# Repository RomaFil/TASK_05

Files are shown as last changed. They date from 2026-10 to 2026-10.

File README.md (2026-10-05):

# TASK_05 — плата Motion Logger для Raspberry Pi 5 і корпус для 3D-друку

Завдання: намалювати в Altium плату-модуль, яка вставляється датчиками й одягається на Raspberry Pi, експортувати її у STEP, відкрити у Fusion і зробити корпус, у якому стоять Raspberry Pi і плата. Окремо — код під Raspberry Pi (поки демонстраційний).

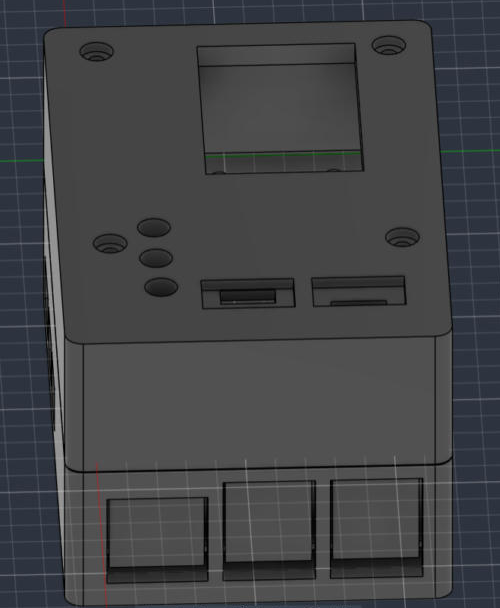
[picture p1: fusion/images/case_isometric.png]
Корпус у Fusion


## Структура репозиторію

```
TASK_05/
├── altium/                      проєкт Altium Designer (відкривати Motion_Logger.PrjPcb)
│   ├── Motion_Logger.PrjPcb     файл проєкту
│   ├── Schematic/Sheet2.SchDoc  схема
│   ├── PCB/PCB2.PcbDoc          плата 85 × 56 мм, 2 шари
│   ├── Library/                 власні бібліотеки: символи (Schlib2) і футпринти (PcbLib2)
│   ├── Fab/                     Gerber + свердління (ZIP) і STEP плати для Fusion
│   ├── Project Outputs for Motion_Logger/   звіт перевірки правил (DRC), 0 помилок
│   └── CAMtastic*.Cam           службові файли Altium для Gerber
├── fusion/                      проєкт Fusion
│   ├── Motion_Logger_Case.f3d   модель (архів Fusion: відкривається через File → Open → Open from my computer)
│   ├── output/                  результат: STL для друку, STEP збірки
│   ├── inputs/                  вхідні STEP: плата з Altium і спрощена модель Pi 5
│   ├── script/                  скрипт Fusion (Python), що будує корпус
│   ├── tools/                   допоміжні скрипти перевірки (Python)
│   └── images/                  картинки: вигляд моделі і перерізи
└── code/                        демонстраційний код для Raspberry Pi (Python), буде змінюватися
```

## 1. Altium: плата Motion Logger

Плата розміром 85 × 56 мм (як Raspberry Pi 5) одягається на гребінку 2×20 Raspberry Pi. Кріпильні отвори ⌀2,7 мм на 58 × 49 мм збігаються з отворами Pi. Товщина 1,6 мм, 2 шари, модулі стоять зверху. Власних джерел живлення на платі нема: 3,3 В беруться з Pi.

Модулі й елементи на платі:

| Позначення | Що це | Інтерфейс |
|---|---|---|
| `U1` | GPS NEO-6M (модуль HW-623) | UART |
| `U2` | GY-87 (HW-290): MPU6050 + HMC5883L + BMP180 | I2C |
| `U3` | ADXL345 (модуль GY-291) | SPI |
| `SW1`, `SW2` | дві кнопки (HW-483, KY-004) | GPIO |
| `D1`–`D3` + `R1`–`R3` | RGB-світлодіод з трьох окремих світлодіодів і резисторів | GPIO |
| `J1` | гніздо 2×20 під Raspberry Pi 5 | — |

### Підключення пінів Pi 5

| Пін `J1` | GPIO | Мережа | Куди |
|---|---|---|---|
| 1, 17 | 3V3 | `VCC` | живлення модулів і кнопок |
| 6, 9, 14, 20, 25, 30, 34, 39 | GND | `GND` | земля |
| 3 / 5 | GPIO2 / GPIO3 | `I2C_SDA` / `I2C_SCL` | GY-87 |
| 7 / 29 | GPIO4 / GPIO5 (uart2) | `UART_TX` / `UART_RX` | GPS |
| 19 / 21 / 23 / 24 | GPIO10 / 9 / 11 / 8 | `SPI_MOSI` / `MISO` / `SCLK` / `CS0` | ADXL345 |
| 11 / 33 | GPIO17 / GPIO13 | `BTN` / `BTN2` | кнопки `SW1` / `SW2` |
| 13 / 15 / 31 | GPIO27 / GPIO22 / GPIO6 | `LED_R` / `LED_G` / `LED_B` | світлодіоди |

Правила проєктування пройдено без порушень (DRC: 0). Звіт: `altium/Project Outputs for Motion_Logger/`.

Файли для виробництва: `altium/Fab/Motion_Logger_Gerber.zip` (шари, контур, свердління металізованих і неметалізованих отворів окремо). STEP для Fusion: `altium/Fab/Motion_Logger_board.step`.

Версія Altium Designer, у якій зроблено проєкт: 26.10.1.

## 2. Fusion: корпус

Корпус складається з **основи** і **кришки**. Усередині: Raspberry Pi 5 на 4 стійках, над ним на стійках M2.5 плата Motion Logger.

Модель збудовано скриптом Fusion (Python API) за розмірами зі STEP плати з Altium і офіційного STEP Raspberry Pi 5. Опис кроків: розділ «Як зроблено» нижче.

Головні розміри (мм; система координат: лівий нижній кут плати = (0;0), Z = 0 — верх плати):

| Що | Значення |
|---|---|
| Зовнішній розмір корпусу | 95,6 × 65,0 × 52,9 |
| Стінки / дно / верх кришки | 3,0 / 3,0 / 4,0 |
| Висота від верху плати Pi до низу плати Motion Logger | 20,0 (довжина стійок M2.5) |
| Висота над платою Motion Logger | 20,0 (гребінка 8,5 + модуль 10 + запас 1,5) |
| Стійки під Pi | ⌀7, висота 3,0, гвинти M2.5 знизу |
| Кришка | 4 гвинти M2.5 згори крізь труби кришки і плату в стійки |

Вікна й отвори:
- Права стіна: Ethernet і два блоки USB Raspberry Pi.
- Нижня стіна: USB-C живлення і два micro-HDMI.
- Ліва стіна: карта microSD.
- Дно: 5 щілин під процесором (пасивне охолодження, кулера нема).
- Кришка: 3 світловоди під світлодіоди, вікно на весь модуль GPS, дві ніші під модулі кнопок зі щілиною для дротів.

Перевірки (скрипти в `fusion/tools/`): перетинів основи і кришки з платою та Pi немає, найменший зазор основи до роз'ємів Pi 0,74 мм, перерізи в `fusion/images/`.

### Друк
Використовуй STL з `fusion/output/`:
- `Case_Base_print.stl` — основа, друкувати як є (дном вниз);
- `Case_Lid_print_flipped.stl` — кришка, уже перевернута верхом на стіл.

Зазори 0,2–0,3 мм і стінки 3 мм — загальні правила, не перевірені на конкретному принтері. Матеріал і принтер на момент створення не обрано.

### Як відкрити й змінити
- Модель: `File → Open → Open from my computer` → `fusion/Motion_Logger_Case.f3d`.
- Змінити розмір: поправ параметри на початку `fusion/script/MotionLoggerCase.py` (`H`, `CAV`, `W`, вікна). У Fusion: `Utilities → Add-Ins → Scripts and Add-Ins` → `+` → `Script or add-in from device` → вибрати папку `fusion/script` → `Run`. Скрипт створить новий документ і запише STL/STEP в `fusion/output/`.

## 3. Код для Raspberry Pi
Папка `code/` містить **демонстраційний** код (`motion_logger_demo.py`): читає MPU6050, ADXL345, GPS і кнопки, пише CSV-лог, показує стан світлодіодом. Він простий, на реальному залізі не перевірений і буде змінюватися. Опис і запуск: [code/README.md](code/README.md).

## Як зроблено корпус (коротко)
1. Плату намальовано в Altium, STEP експортовано (`altium/Fab/Motion_Logger_board.step`). У ньому лише плата, гніздо `J1`, резистори й світлодіоди; виводи резисторів і світлодіодів звисали на 27 мм униз.
2. Офіційний STEP Raspberry Pi 5 (Raspberry Pi Ltd, ліцензія MIT) завважкий (77 МБ, 2689 тіл). З нього зчитано габарити роз'ємів і зроблено спрощену модель `fusion/inputs/pi5_proxy.step` (`fusion/tools/make_pi5_proxy.py`). У платі лишено тіло плати, гніздо й колби світлодіодів без виводів (`fusion/tools/make_plate_input.py`).
3. Висоту між Pi і платою розраховано за STEP: роз'єми USB стоять на 16,2 мм над платою Pi, пластик гребінки Pi 2,57 мм, штирі ще 6,0 мм.
4. Скрипт `fusion/script/MotionLoggerCase.py` імпортує обидва STEP, ставить їх у потрібні місця й будує основу та кришку (тіла з об'ємними логічними операціями), експортує STL і STEP.
5. Результат перевірено в Python (OpenCascade): перетини, зазори, перерізи.

Під час роботи використовувався ШІ-асистент Claude (Anthropic): він читав STEP-файли, рахував розміри, писав скрипт Fusion і перевірки. Рішення щодо конструкції (висота стека, гвинти, кнопки в кришці, живлення тільки через USB-C Pi, вікно GPS, товщина стінок) ухвалював я.

## Ліцензії та джерела
- 3D-модель Raspberry Pi 5: Raspberry Pi Ltd, MIT, <https://datasheets.raspberrypi.com/rpi5/RaspberryPi5-step.zip> (в репозиторії лише спрощена модель, зроблена з її розмірів).

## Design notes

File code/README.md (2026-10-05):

# Код для Raspberry Pi 5 (демонстрація)

> **Це лише демонстрація. Код простий, на реальному залізі не перевірений і буде змінюватися.**
> Фінальна версія з'явиться пізніше (буфер, потоки, фільтр руху, запуск при старті системи).

Що робить `motion_logger_demo.py`: раз на секунду читає датчики й пише рядок у CSV-лог.

| Що | Як | Піни / адреса |
|---|---|---|
| MPU6050 (модуль GY-87) | I2C1, бібліотека `smbus2` | пін 3 (SDA), пін 5 (SCL), адреса `0x68` |
| ADXL345 (модуль GY-291) | SPI0, бібліотека `spidev` | піни 19, 21, 23, CE0 = пін 24 |
| GPS NEO-6M | UART, бібліотека `pyserial`, рядки `$..RMC` з перевіркою контрольної суми | піни 7 (TX), 29 (RX), порт `/dev/ttyAMA2` |
| Кнопка 1 / 2 | GPIO17 / GPIO13, `libgpiod` | пауза запису / позначка `MARK` у логу |
| Світлодіод | GPIO27 (червоний), GPIO22 (зелений), GPIO6 (синій) | червоний — нема GPS-фіксації, зелений — є, синій — запис |

Якщо датчик чи бібліотека недоступні, програма пише про це і працює далі без нього (у лозі порожні значення).

## Як запустити (не перевірено на Pi)

1. У `/boot/firmware/config.txt` увімкнути інтерфейси й перезавантажити:
   ```
   dtparam=i2c_arm=on
   dtparam=spi=on
   dtoverlay=uart2-pi5
   ```
   Назву overlay `uart2-pi5` перевір командою `ls /boot/firmware/overlays | grep uart`.
2. Встановити бібліотеки:
   ```
   sudo apt install python3-libgpiod
   pip install -r requirements.txt --break-system-packages
   ```
3. Перевірити датчики: `i2cdetect -y 1` (має бути `68`), `ls /dev/spidev0.0`, `ls /dev/ttyAMA*`.
4. Запустити:
   ```
   python3 motion_logger_demo.py
   ```
   Вихід: `Ctrl+C`. Лог: `motion_log.csv` у поточній папці (інша назва: змінна `LOG_FILE`; інший порт GPS: змінна `GPS_PORT`).

## Перевірка розбору даних (без Raspberry Pi)
```
python test_parsers.py
```
Перевіряє контрольну суму NMEA, розбір `$GPRMC` і перерахунок «сирих» байтів MPU6050 та ADXL345 у фізичні величини. Працює на будь-якому комп'ютері.

## Що не перевірено
- Робота на реальному Raspberry Pi 5 з платою (усі піни взято з таблиці підключень, див. [головний README](../README.md#підключення-пінів-pi-5)).
- Назва overlay UART і порт `/dev/ttyAMA2`.
- Чи дає натиснута кнопка 1 (`BUTTON_ACTIVE_HIGH = True` у коді): залежить від модуля KY-004.
- Номер `gpiochip`: програма шукає чип RP1 автоматично, запасний варіант `/dev/gpiochip0`.

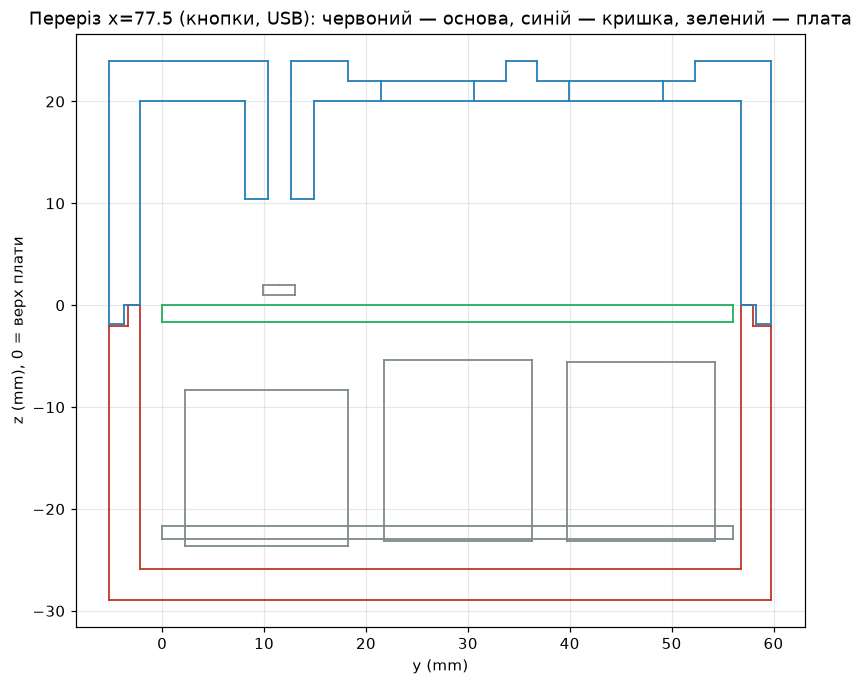
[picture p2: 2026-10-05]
fusion/images/sec_x775.png

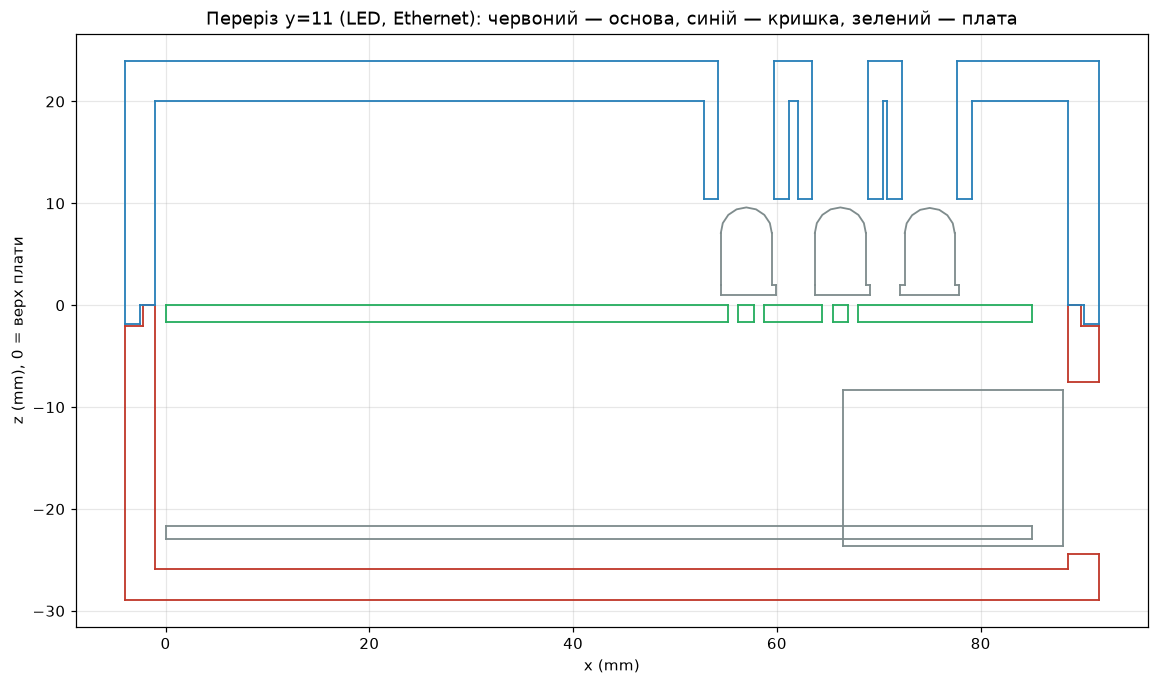
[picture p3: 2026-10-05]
fusion/images/sec_y11.png

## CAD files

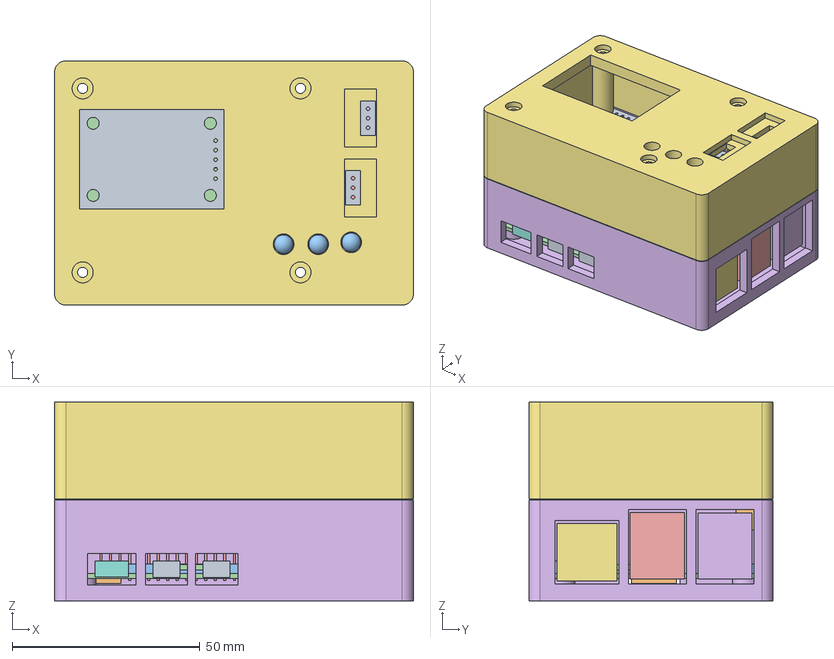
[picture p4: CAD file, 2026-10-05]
fusion/output/Motion_Logger_case_assembly.step
95.6 x 65.0 x 52.9 mm

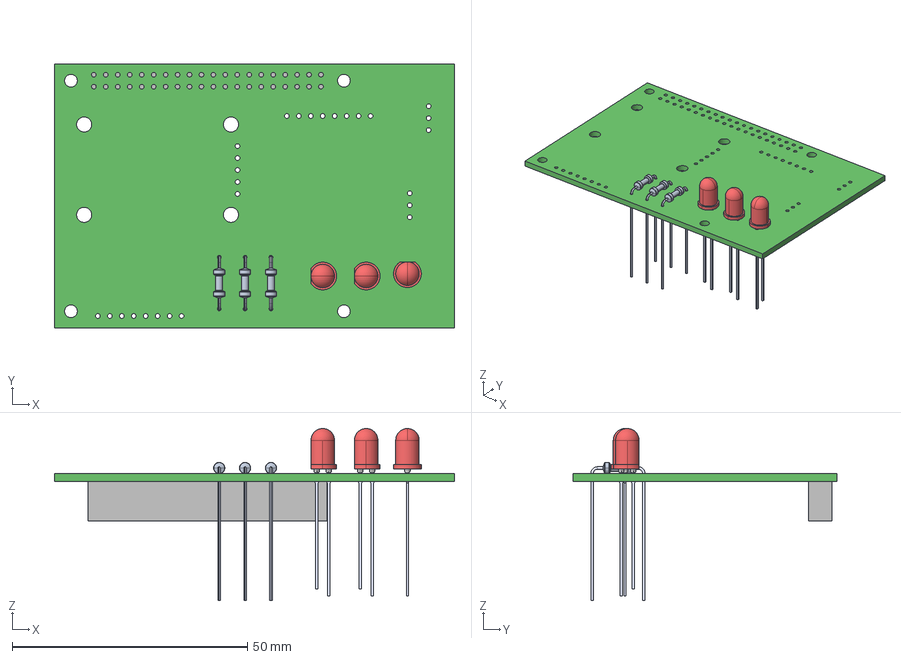
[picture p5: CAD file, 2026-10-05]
altium/Fab/Motion_Logger_board.step
85.0 x 56.0 x 36.6 mm
Extruded
WP7113ID_WP7113ID x 3

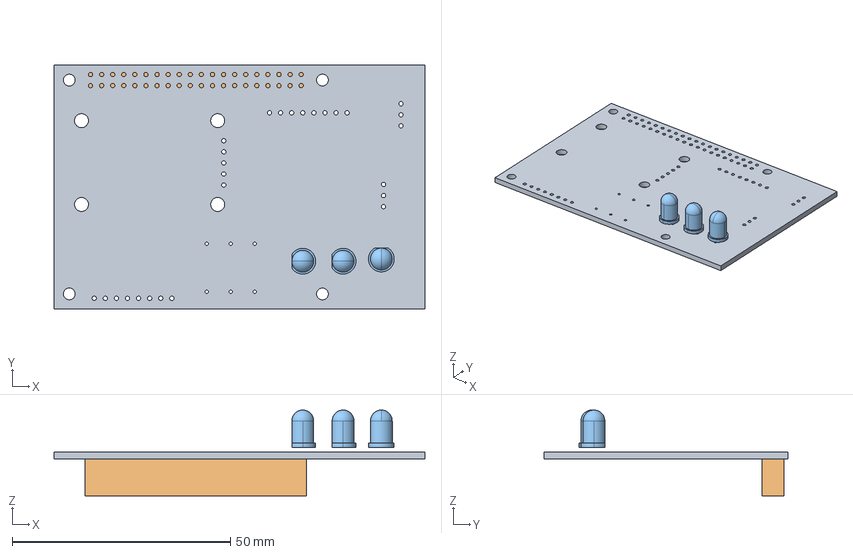
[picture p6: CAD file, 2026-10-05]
fusion/inputs/plate_clean.step
85.0 x 56.0 x 19.7 mm

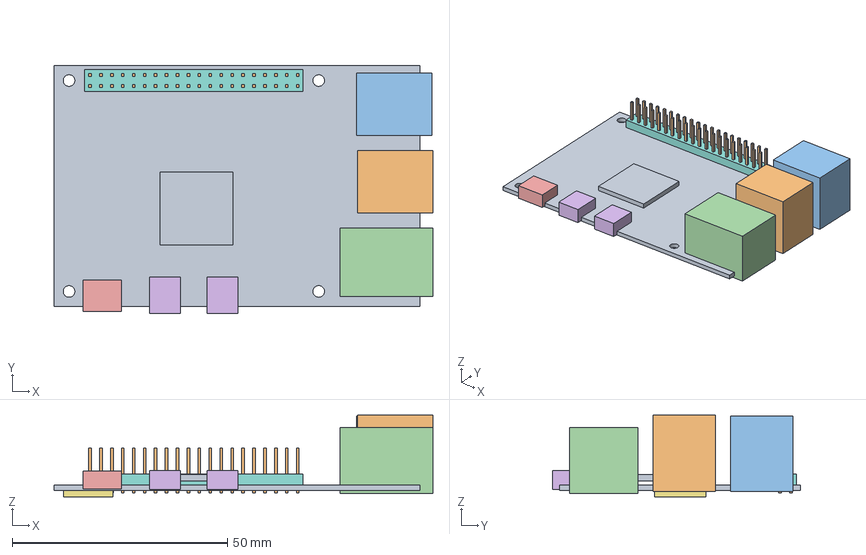
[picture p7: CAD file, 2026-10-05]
fusion/inputs/pi5_proxy.step
88.0 x 57.6 x 19.0 mm

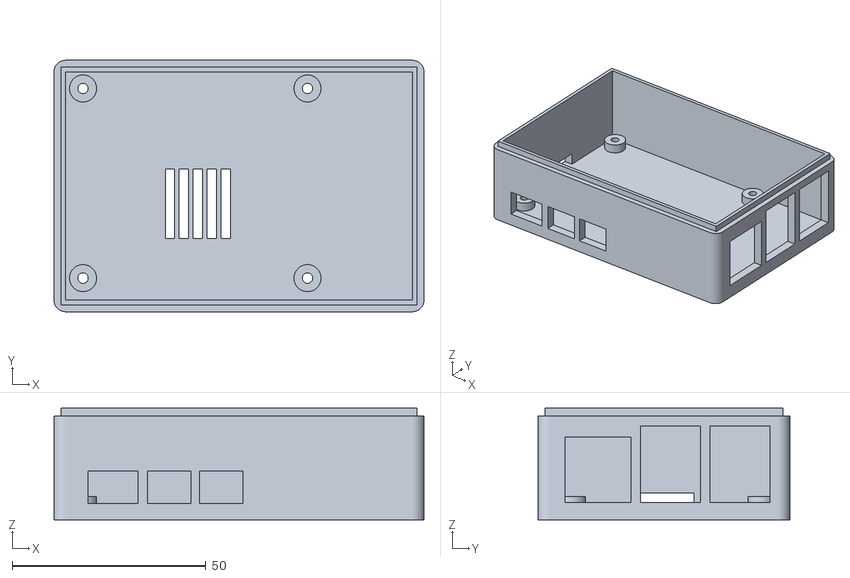
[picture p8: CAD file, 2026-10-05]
fusion/output/Case_Base_print.stl
95.6 x 65.0 x 28.9

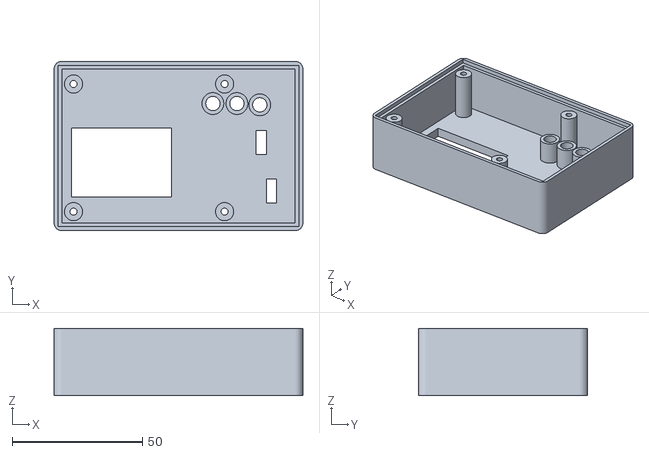
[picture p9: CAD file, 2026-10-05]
fusion/output/Case_Lid_print_flipped.stl
95.6 x 65.0 x 25.8

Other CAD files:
fusion/Motion_Logger_Case.f3d

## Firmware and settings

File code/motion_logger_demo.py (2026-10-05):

#!/usr/bin/env python3
"""Motion Logger: ДЕМОНСТРАЦІЙНИЙ код для Raspberry Pi 5 (буде змінюватись).

Раз на секунду читає датчики, пише рядок у CSV-лог і показує стан світлодіодом:
  - MPU6050 (модуль GY-87, I2C, адреса 0x68): прискорення, швидкість обертання, температура;
  - ADXL345 (модуль GY-291, SPI0, CE0): прискорення;
  - GPS NEO-6M (UART): координати, швидкість, чи є фіксація;
  - кнопка 1 (GPIO17): пауза / відновлення запису;
  - кнопка 2 (GPIO13): позначка «MARK» у наступному рядку логу;
  - світлодіод: червоний — нема GPS-фіксації, зелений — є, синій блимає при записі.

Піни взято з таблиці підключень плати (altium/, README.md). На реальному залізі НЕ перевірено.
Якщо якийсь датчик або бібліотека недоступні, програма це пише й продовжує без нього.
"""
import csv
import glob
import os
import sys
import time

# ---------------- налаштування (піни за схемою плати) ----------------
LED_R, LED_G, LED_B = 27, 22, 6          # GPIO світлодіодів (через резистори на платі)
BTN1, BTN2 = 17, 13                      # GPIO кнопок
BUTTON_ACTIVE_HIGH = True                # припущення: натиснута кнопка дає 1; перевірити на залізі
I2C_BUS, MPU_ADDR = 1, 0x68              # I2C1 (піни 3 і 5), AD0 на землі
SPI_BUS, SPI_CS = 0, 0                   # SPI0, CE0 (пін 24)
GPS_PORT = os.environ.get("GPS_PORT", "/dev/ttyAMA2")   # uart2 на GPIO4/5; назву overlay не перевірено
GPS_BAUD = 9600
LOG_FILE = os.environ.get("LOG_FILE", "motion_log.csv")
PERIOD_S = 1.0


# ---------------- розбір даних (працює і без заліза, є тести) ----------------
def to_signed16(hi, lo):
    v = (hi << 8) | lo
    return v - 65536 if v & 0x8000 else v


def mpu6050_convert(raw14):
    """14 байт з регістра 0x3B → (accel_g[3], temp_c, gyro_dps[3]); діапазони ±2 g і ±250 °/с."""
    w = [to_signed16(raw14[i], raw14[i + 1]) for i in range(0, 14, 2)]
    accel = tuple(round(v / 16384.0, 4) for v in w[0:3])
    temp = round(w[3] / 340.0 + 36.53, 2)
    gyro = tuple(round(v / 131.0, 3) for v in w[4:7])
    return accel, temp, gyro


def adxl345_convert(raw6):
    """6 байт з регістра 0x32 → прискорення в g (повна роздільність ≈ 3,9 мг/біт)."""
    return tuple(round(to_signed16(raw6[i + 1], raw6[i]) * 0.0039, 4) for i in range(0, 6, 2))


def nmea_checksum_ok(line):
    """Перевірка контрольної суми NMEA: XOR символів між '$' і '*'."""
    if not line.startswith("$") or "*" not in line:
        return False
    body, _, tail = line[1:].partition("*")
    calc = 0
    for ch in body:
        calc ^= ord(ch)
    try:
        return calc == int(tail[:2], 16)
    except ValueError:
        return False


def _deg(value, hemi):
    """ddmm.mmmm → градуси."""
    if not value:
        return None
    dot = value.index(".")
    deg = float(value[:dot - 2]) + float(value[dot - 2:]) / 60.0
    return -deg if hemi in ("S", "W") else deg


def parse_rmc(line):
    """$GPRMC / $GNRMC → dict(fix, lat, lon, speed_kmh) або None, якщо рядок не підходить."""
    if not nmea_checksum_ok(line):
        return None
    f = line.split("*")[0].split(",")
    if f[0][3:] != "RMC" or len(f) < 8:
        return None
    fix = f[2] == "A"
    return {
        "fix": fix,
        "lat": _deg(f[3], f[4]) if fix else None,
        "lon": _deg(f[5], f[6]) if fix else None,
        "speed_kmh": round(float(f[7]) * 1.852, 2) if fix and f[7] else None,
    }


# ---------------- робота із залізом ----------------
class Leds:
    """Світлодіоди й кнопки через libgpiod 2.x (пакет python3-libgpiod)."""

    def __init__(self):
        self.req = None
        try:
            import gpiod
            from gpiod.line import Bias, Direction, Value
            self.Value = Value
            path = self._find_chip(gpiod)
            out = gpiod.LineSettings(direction=Direction.OUTPUT, output_value=Value.INACTIVE)
            inp = gpiod.LineSettings(direction=Direction.INPUT,
                                     bias=Bias.PULL_DOWN if BUTTON_ACTIVE_HIGH else Bias.PULL_UP)
            self.req = gpiod.request_lines(path, consumer="motion-logger", config={
                LED_R: out, LED_G: out, LED_B: out, BTN1: inp, BTN2: inp})
            print("GPIO: чип", path)
        except Exception as e:
            print("GPIO недоступний:", e)

    @staticmethod
    def _find_chip(gpiod):
        # На Pi 5 піни гребінки належать мікросхемі RP1; номер gpiochip залежить від ядра.
        for path in sorted(glob.glob("/dev/gpiochip*")):
            try:
                if "rp1" in gpiod.Chip(path).get_info().label.lower():
                    return path
            except Exception:
                pass
        return "/dev/gpiochip0"

    def set(self, r=False, g=False, b=False):
        if self.req:
            V = self.Value
            self.req.set_values({LED_R: V.ACTIVE if r else V.INACTIVE,
                                 LED_G: V.ACTIVE if g else V.INACTIVE,
                                 LED_B: V.ACTIVE if b else V.INACTIVE})

    def pressed(self, pin):
        if not self.req:
            return False
        active = self.req.get_value(pin) == self.Value.ACTIVE
        return active if BUTTON_ACTIVE_HIGH else not active


class Mpu6050:
    def __init__(self):
        self.bus = None
        try:
            from smbus2 import SMBus
            self.bus = SMBus(I2C_BUS)
            self.bus.write_byte_data(MPU_ADDR, 0x6B, 0x00)   # вийти зі сну
            print("MPU6050: ок")
        except Exception as e:
            print("MPU6050 недоступний:", e)
            self.bus = None

    def read(self):
        if not self.bus:
            return None
        try:
            return mpu6050_convert(self.bus.read_i2c_block_data(MPU_ADDR, 0x3B, 14))
        except Exception:
            return None


class Adxl345:
    def __init__(self):
        self.spi = None
        try:
            import spidev
            self.spi = spidev.SpiDev()
            self.spi.open(SPI_BUS, SPI_CS)
            self.spi.max_speed_hz = 1_000_000
            self.spi.mode = 0b11                              # ADXL345 працює в режимі SPI 3
            devid = self.spi.xfer2([0x80 | 0x00, 0x00])[1]   # регістр DEVID, має бути 0xE5
            if devid != 0xE5:
                raise RuntimeError("DEVID=0x%02X, очікувалось 0xE5" % devid)
            self.spi.xfer2([0x2D, 0x08])                      # POWER_CTL: режим вимірювання
            self.spi.xfer2([0x31, 0x08])                      # DATA_FORMAT: повна роздільність, ±2 g
            print("ADXL345: ок")
        except Exception as e:
            print("ADXL345 недоступний:", e)
            self.spi = None

    def read(self):
        if not self.spi:
            return None
        try:
            return adxl345_convert(self.spi.xfer2([0xC0 | 0x32] + [0] * 6)[1:])
        except Exception:
            return None


class Gps:
    def __init__(self):
        self.ser = None
        self.last = {"fix": False, "lat": None, "lon": None, "speed_kmh": None}
        try:
            import serial
            self.ser = serial.Serial(GPS_PORT, GPS_BAUD, timeout=0.2)
            print("GPS: порт", GPS_PORT)
        except Exception as e:
            print("GPS недоступний:", e)

    def poll(self):
        """Зчитує все, що накопичилось у порту, і оновлює останнє значення з $xxRMC."""
        if not self.ser:
            return self.last
        try:
            for raw in self.ser.read(self.ser.in_waiting or 1).decode("ascii", "ignore").splitlines():
                data = parse_rmc(raw.strip())
                if data:
                    self.last = data
        except Exception:
            pass
        return self.last


# ---------------- головний цикл ----------------
def main():
    leds, mpu, adxl, gps = Leds(), Mpu6050(), Adxl345(), Gps()
    new_file = not os.path.exists(LOG_FILE)
    log = open(LOG_FILE, "a", newline="", encoding="utf-8")
    out = csv.writer(log)
    if new_file:
        out.writerow(["time", "mark", "mpu_ax_g", "mpu_ay_g", "mpu_az_g", "mpu_temp_c",
                      "gyro_x_dps", "gyro_y_dps", "gyro_z_dps",
                      "adxl_x_g", "adxl_y_g", "adxl_z_g", "gps_fix", "lat", "lon", "speed_kmh"])
    paused, mark, was_pressed1, was_pressed2 = False, False, False, False
    print("Запис у", LOG_FILE, "(Ctrl+C — вихід; кнопка 1 — пауза, кнопка 2 — позначка)")
    try:
        while True:
            t0 = time.time()
            p1, p2 = leds.pressed(BTN1), leds.pressed(BTN2)
            if p1 and not was_pressed1:
                paused = not paused
                print("пауза" if paused else "запис відновлено")
            if p2 and not was_pressed2:
                mark = True
            was_pressed1, was_pressed2 = p1, p2

            fix = gps.poll()
            if not paused:
                m, a = mpu.read(), adxl.read()
                accel, temp, gyro = m if m else ((None,) * 3, None, (None,) * 3)
                row = [time.strftime("%Y-%m-%d %H:%M:%S"), "MARK" if mark else "", *accel, temp, *gyro,
                       *(a if a else (None,) * 3), int(fix["fix"]), fix["lat"], fix["lon"], fix["speed_kmh"]]
                out.writerow(row)
                log.flush()
                print(row)
                mark = False
                leds.set(r=not fix["fix"], g=fix["fix"], b=True)   # синій блимає разом із записом
                time.sleep(0.1)
            leds.set(r=not fix["fix"] and not paused, g=fix["fix"] and not paused, b=False)
            time.sleep(max(0.0, PERIOD_S - (time.time() - t0)))
    except KeyboardInterrupt:
        print("\nвихід")
    finally:
        leds.set()
        log.close()


if __name__ == "__main__":
    sys.exit(main())

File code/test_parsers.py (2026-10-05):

"""Прості перевірки розбору даних. Працюють на будь-якому комп'ютері, без Raspberry Pi: python test_parsers.py"""
import motion_logger_demo as d

# класичний приклад NMEA-рядка зі специфікації, контрольна сума *6A
RMC = "$GPRMC,123519,A,4807.038,N,01131.000,E,022.4,084.4,230394,003.1,W*6A"
assert d.nmea_checksum_ok(RMC)
assert not d.nmea_checksum_ok(RMC.replace("123519", "123518"))
r = d.parse_rmc(RMC)
assert r["fix"] and abs(r["lat"] - 48.1173) < 1e-4 and abs(r["lon"] - 11.5167) < 1e-4
assert abs(r["speed_kmh"] - 22.4 * 1.852) < 0.01

# без фіксації (статус V) координат нема
nofix = "$GPRMC,123519,V,,,,,,,230394,,*"
body = nofix[1:-1]
chk = 0
for ch in body:
    chk ^= ord(ch)
assert d.parse_rmc("$" + body + "*%02X" % chk)["fix"] is False

# MPU6050: 1 g по осі Z, 0 °/с, температура 36,53 °C при сирому 0
raw = [0, 0, 0, 0, 0x40, 0x00] + [0, 0] + [0] * 6
accel, temp, gyro = d.mpu6050_convert(raw)
assert accel == (0.0, 0.0, 1.0) and temp == 36.53 and gyro == (0.0, 0.0, 0.0)

# ADXL345: молодший байт першим; 256 відліків ≈ 1 g (0,0039 g/біт)
assert d.adxl345_convert([0x00, 0x01, 0, 0, 0xFF, 0xFF]) == (0.9984, 0.0, -0.0039)
print("усі перевірки пройдено")

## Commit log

2026-10-05 Motion Logger: проєкт Altium, корпус у Fusion, README
    Плата 85x56 під Raspberry Pi 5 (Altium), корпус для 3D-друку (Fusion, скрипт Python), STL/STEP, перевірки, структура для коду.
    [Case_Base_print.stl, Case_Lid_print_flipped.stl, Motion_Logger.PrjPcb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]
2026-10-05 Демонстраційний код для Raspberry Pi (датчики, GPS, кнопки, світлодіод) і тести розбору
    Простий код, на залізі не перевірений, буде змінюватися.
2026-10-05 Вимкнено перетворення кінців рядків (.gitattributes), щоб файли Altium лишились байт-в-байт як оригінал
    [Motion_Logger.PrjPcb, Motion_Logger_board.step, Motion_Logger_case_assembly.step]
2026-10-05 Додано решту згенерованих файлів Altium (щоб проєкт не показував відсутніх документів)
    [PCB2.GBL, PCB2.GBO, PCB2.GBS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]
2026-10-13 Плата v3 за зауваженнями викладача, файли для виробництва під pcb24, корпус v3 (товста кришка, ніші під кнопки), PDF для примірки, оновлений README
2026-10-27 Корпус v4: заокруглені кути й ребра, соти для вентиляції, вигравіюваний напис, нові зображення
    - кути R5, ребро біля столу з фаскою 45 градусів і згладженням (друк без підтримок)
    - соти на задній і лівій стінках основи та на верху кришки
    - напис AJAX / MOTION LOGGER глибиною 0,7 мм на кришці
    - скрипт знімає зображення моделі, Pi імпортується після скруглень (інакше зсув скидався)
    - оновлено STL, STEP, лог і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
